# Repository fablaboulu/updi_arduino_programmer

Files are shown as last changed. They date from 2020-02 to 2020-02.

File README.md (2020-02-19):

# Description
This board is a updi programmer that utilizes Arduino IDE to program AVR microcontroller.
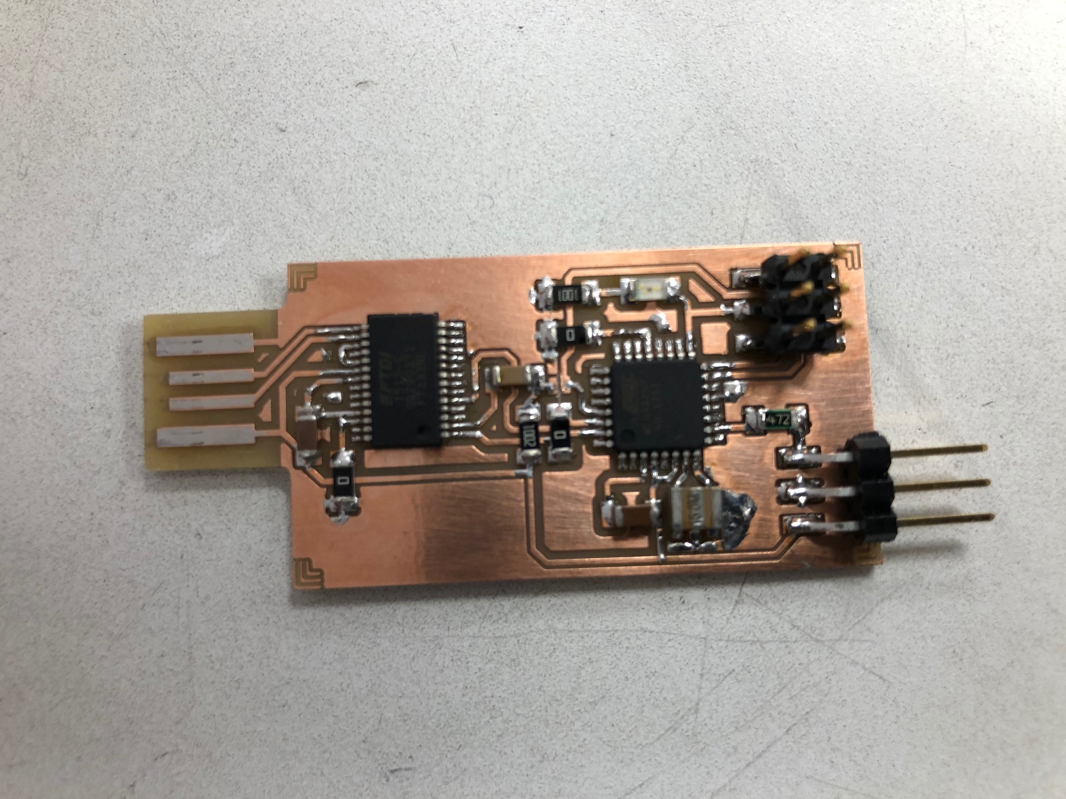
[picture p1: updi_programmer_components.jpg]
UPDI Programmer using Arduino IDE


# Instructions
* Use the Eagle files included in order to create the board to mill. In addition, the '.png' files to be used with [mods](http://mods.cba.mit.edu/) are included.
 
## Files
* [Eagle Board file](updi_programmer.brd)
* [Eagle Schematics file](updi_programmer.sch)
* [Components](updi_programmer_components.jpg)
* [Interior](updi_programmer_outline.png)
* [Traces](updi_programmer_traces.png)
* [Calibration](updi_programmer_calib.png)
## Milling
For milling we use a Roland SRM-20 with a 0.2-0.5 mm V-milling bit. The (updi_programmer_calib)[calibration file] was used for calibrating the milling depth to reach the correct milling width with a V-shape milling bit. 

When calculating the toolpaths with [mods](http://mods.cba.mit.edu/) We used 0.23 mm as the tool width for traces and calibration and 1 mm for the outline.

## Board dimensions:
*dpi*: 2400

*px*: 5932 x 2575

*mm*: 62.780 x 27.252

*in*: 2.472 x 1.073

# Links
* We followed the tutorials found at in:
  * [https://github.com/SpenceKonde/megaTinyCore/blob/master/MakeUPDIProgrammer.md](https://github.com/SpenceKonde/megaTinyCore/blob/master/MakeUPDIProgrammer.md)
  * [https://www.pcbway.com/project/shareproject/A_USB_stick_sized_UPDI_programmer.html](https://www.pcbway.com/project/shareproject/A_USB_stick_sized_UPDI_programmer.html)
  * [https://github.com/ElTangas/jtag2updi](https://github.com/ElTangas/jtag2updi)
  * [https://www.electronics-lab.com/project/getting-started-with-the-new-attiny-chips-programming-the-microchips-0-series-and-1-series-attiny-with-the-arduino-ide/](https://www.electronics-lab.com/project/getting-started-with-the-new-attiny-chips-programming-the-microchips-0-series-and-1-series-attiny-with-the-arduino-ide/)

# Authors
* Antti Mäntyniemi: antti.mantyniemi@oulu.fi

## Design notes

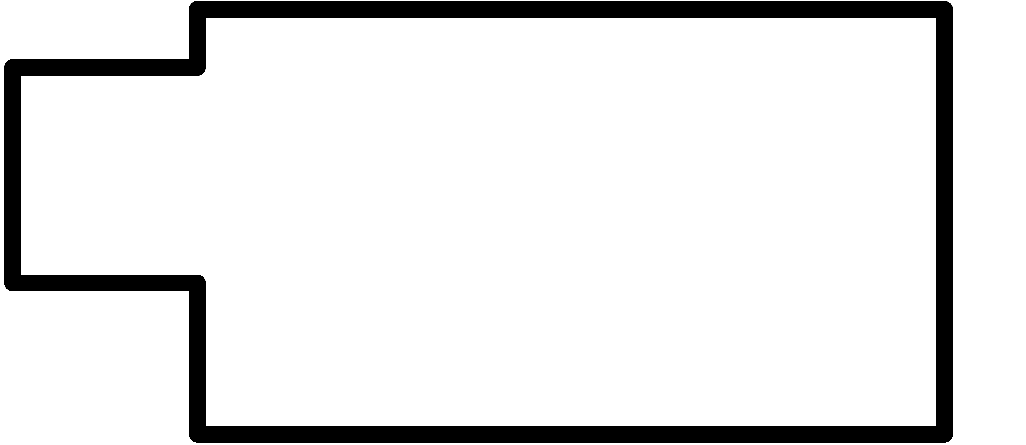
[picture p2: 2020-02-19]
updi_programmer_outline.png

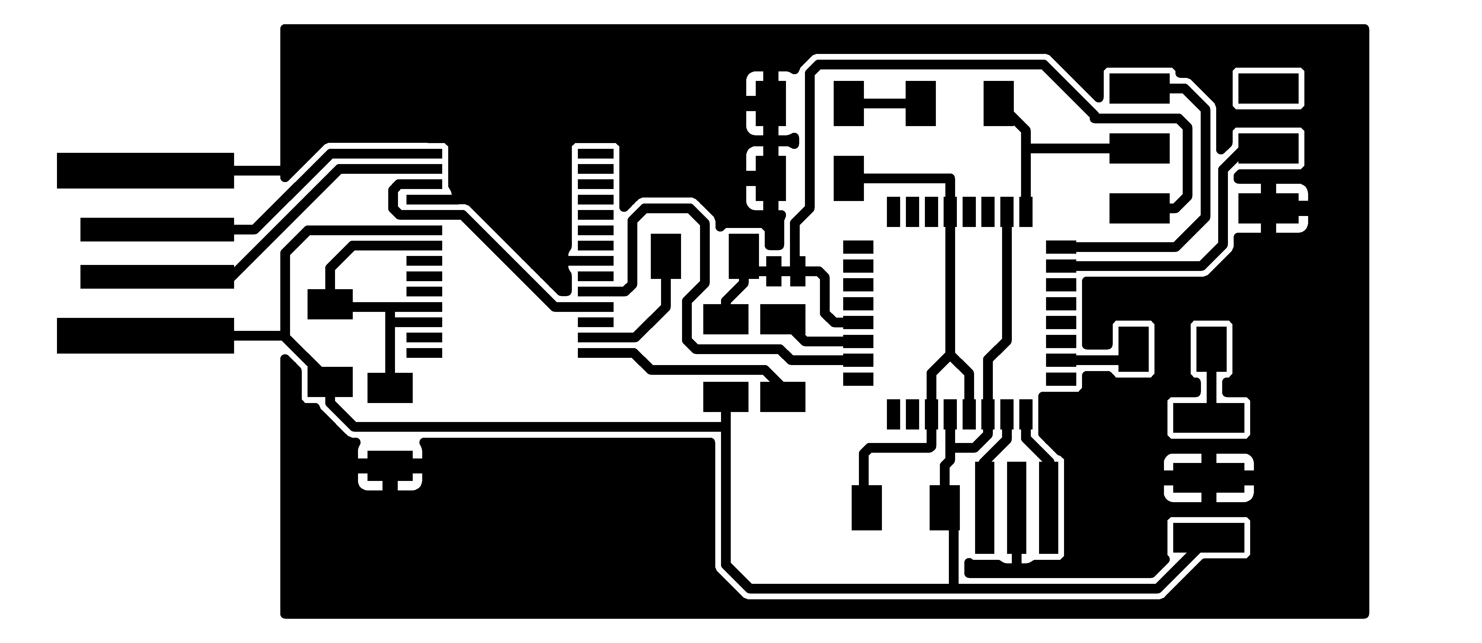
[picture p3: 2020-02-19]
updi_programmer_traces.png

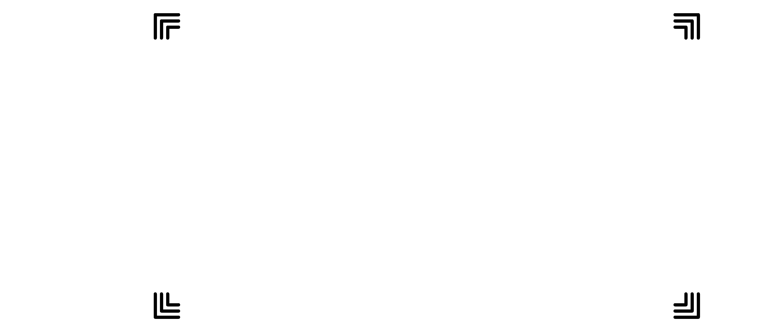
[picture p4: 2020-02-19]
updi_programmer_calib.png

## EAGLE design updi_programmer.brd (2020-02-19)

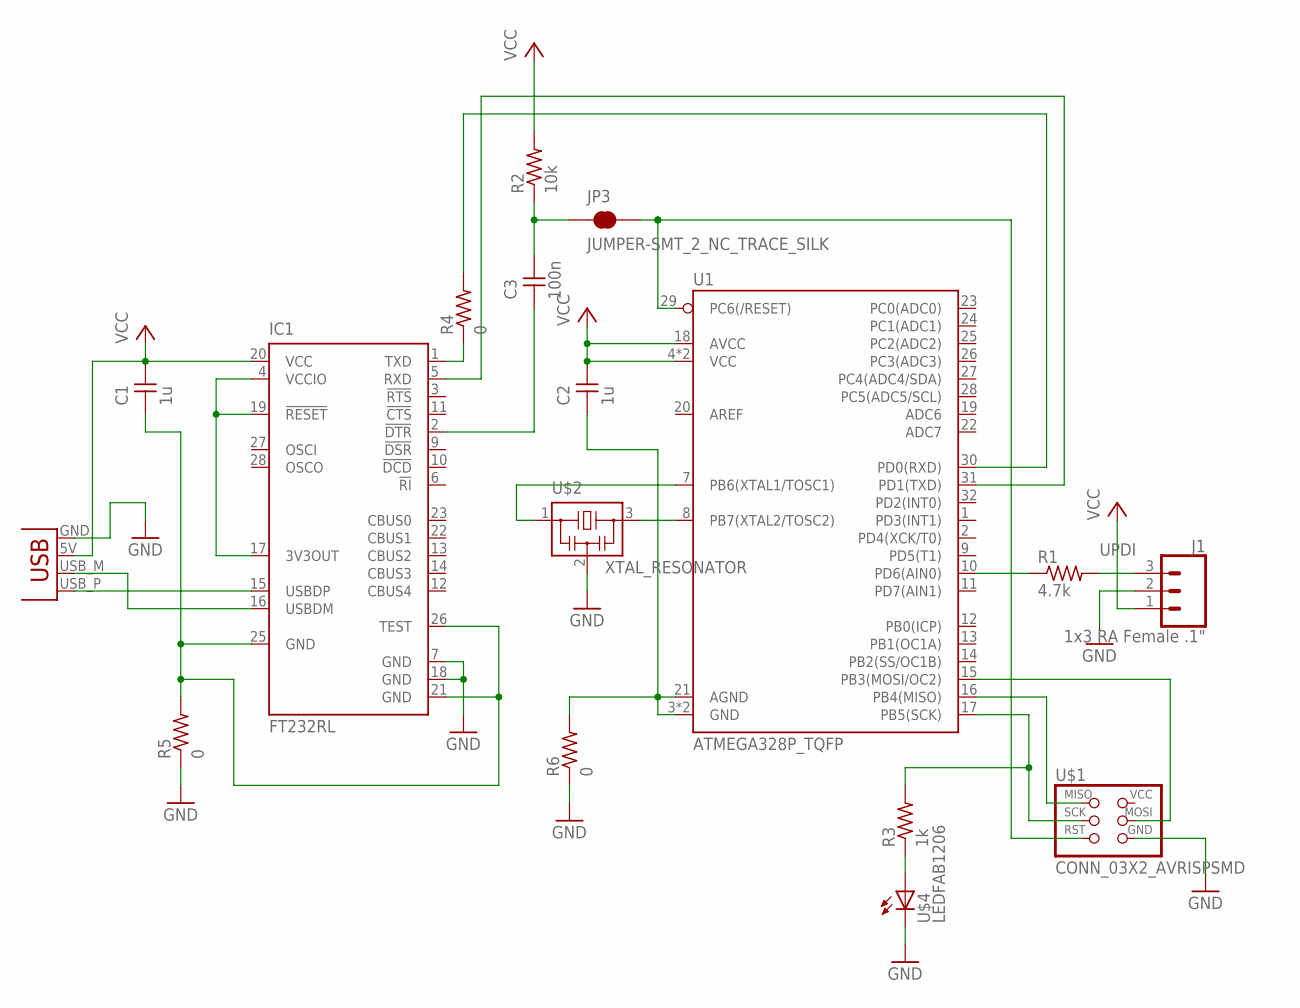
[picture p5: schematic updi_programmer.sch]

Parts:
C1, C2: 1u; C1206FAB
C3: 100n; C1206FAB
IC1: FT232RL; SSOP28
J1: 1x3 RA Female .1"; 1X03_SMD_RA_FEMALE
JP3: JUMPER-SMT_2_NC_TRACE_SILK; SMT-JUMPER_2_NC_TRACE_SILK
R1: 4.7k; R1206FAB
R2: 10k; R1206FAB
R3: 1k; R1206FAB
R4, R5, R6: 0; R1206FAB
U1: ATMEGA328P_TQFP; TQFP32-08
U$1: CONN_03X2_AVRISPSMD; 2X03SMD
U$2: XTAL_RESONATOR; EFOBM
U$4: LEDFAB1206; LED1206FAB
X1: CONN_USBPCB; USB-A-PCB

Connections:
GND: IC1.7 (GND), IC1.18 (GND), J1.2, R5.1, R6.1, U$1.6 (GND), U$2.2, U$4.2 (C), X1.GND
unnamed: IC1.1 (TXD), R4.1
unnamed: IC1.4 (VCCIO), IC1.17 (3V3OUT), IC1.19 (!RESET)
unnamed: IC1.15 (USBDP), X1.USB_P (D+)
unnamed: IC1.16 (USBDM), X1.USB_M (D-)
unnamed: U1.8 (PB7(XTAL2/TOSC2)), U$2.3
unnamed: U1.7 (PB6(XTAL1/TOSC1)), U$2.1
unnamed: R3.1, U$4.1 (A)
unnamed: C3.2, JP3.1, R2.1
unnamed: U1.16 (PB4(MISO)), U$1.1 (MISO)
unnamed: R1.1, U1.10 (PD6(AIN0))
unnamed: R3.2, U1.17 (PB5(SCK)), U$1.3 (SCK)
unnamed: U1.15 (PB3(MOSI/OC2)), U$1.4 (MOSI)
unnamed: JP3.2, U1.29 (PC6(/RESET)), U$1.5 (RST)
unnamed: C3.1, IC1.2 (!DTR)
unnamed: R4.2, U1.30 (PD0(RXD))
unnamed: IC1.5 (RXD), U1.31 (PD1(TXD))
unnamed: C2.1, R6.2, U1.3 (GND), U1.5 (GND), U1.21 (AGND)
unnamed: C1.1, IC1.21 (GND), IC1.25 (GND), IC1.26 (TEST), R5.2
UPDI: J1.3, R1.2
VCC: C1.2, C2.2, IC1.20 (VCC), J1.1, R2.2, U1.4 (VCC), U1.6 (VCC), U1.18 (AVCC), X1.5V (VBUS)

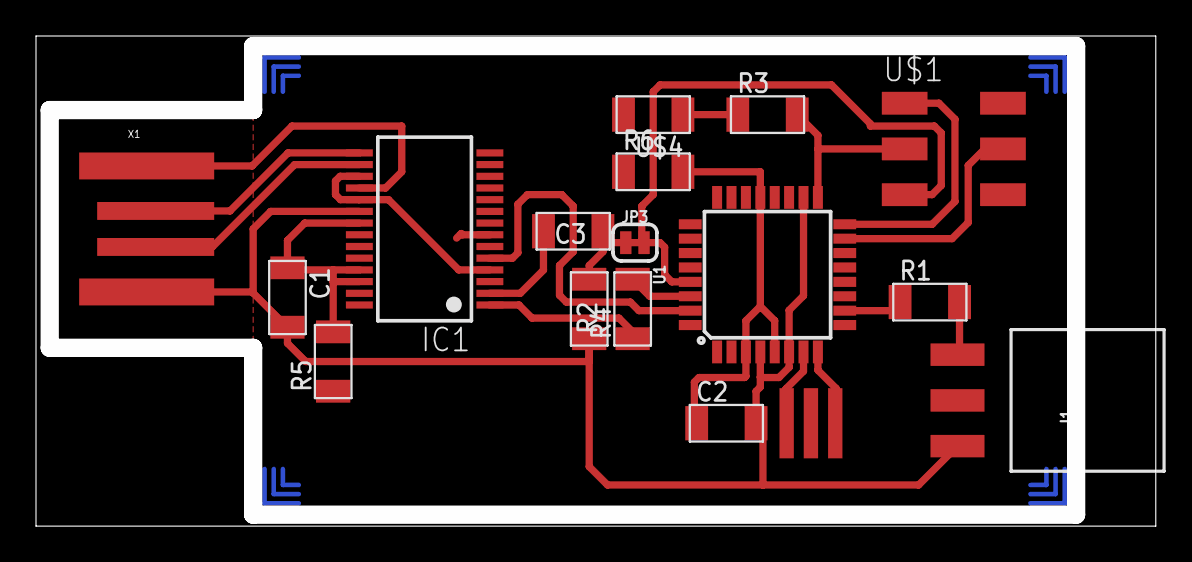
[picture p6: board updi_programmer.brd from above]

Board: 2 copper layers, 62.2 x 27.2 mm, 17 parts (0 on the bottom side), 21 nets.

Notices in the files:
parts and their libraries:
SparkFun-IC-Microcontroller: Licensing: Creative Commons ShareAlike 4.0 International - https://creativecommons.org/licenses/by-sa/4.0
